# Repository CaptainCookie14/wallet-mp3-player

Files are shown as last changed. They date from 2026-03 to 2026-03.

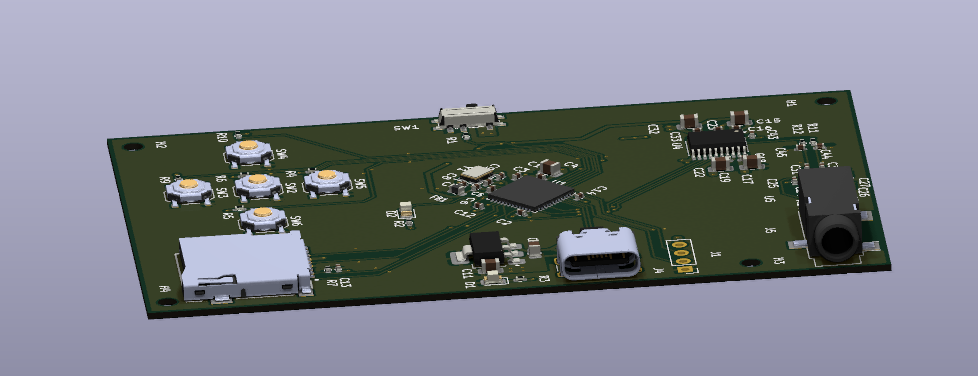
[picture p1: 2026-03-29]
photos/Screenshot 2026-03-28 175809.png

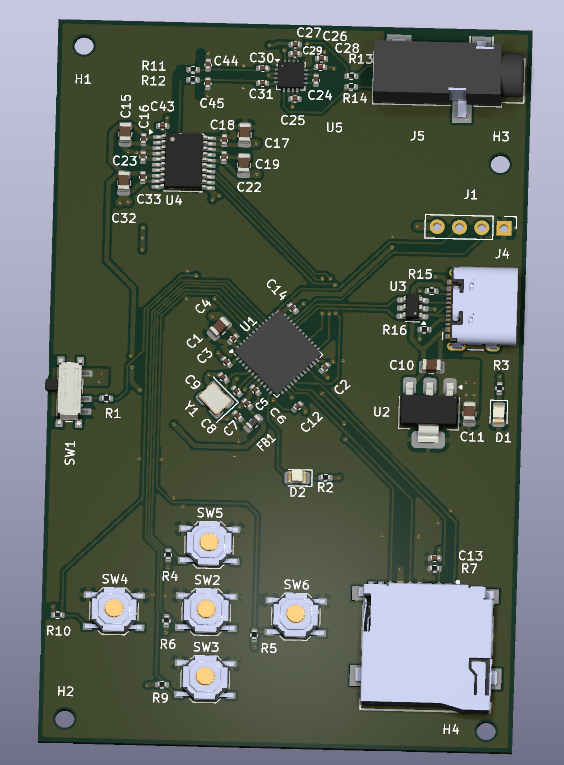
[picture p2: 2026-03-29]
photos/Screenshot 2026-03-28 175754.png

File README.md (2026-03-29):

# wallet-mp3-player
This project is a small, portable MP3 player, designed to be roughly the size of a credit card. This project is all about minimal power consumption, small PCB design, and ease of use for the player.

HOW TO USE IT Insert a micro SD card containing MP3 or WAV files into the device. Turn it on using the battery and play the songs using the buttons. It does not require a phone or computer to play songs. Users can play, pause, and skip songs, and also change the volume using the buttons.



Features

Plays MP3 audio files Ultra-compact PCB design (credit card sized) Button-based controls (play/pause, next, previous, volume) Supports microSD storage for music files Low power consumption for portable devices Optional output for headphones or small speakers

HOW IT WORKS:

It is composed of a microcontroller, which reads the audio files from a storage module, usually a microSD card. The microcontroller then sends the decoded audio to an amplifier for output.

The buttons are always being read by the microcontroller, which controls the state of the player, the songs being played, and the volume.

HARDWARE USED:

-Microcontroller ( STM32F411CEU6x )
- Micro SD card module
- Audio DAC module
- Small audio amplifier
- Tactile and low-profile buttons
- Lithium battery and charging circuit
- PCB designed in KiCad

WIRING/CONNECTIONS:

- Micro SD card module is connected through SPI
- Audio module is connected through I2S or analog pins
- Buttons are connected to digital GPIOs with pull-ups
- Battery is connected through power management circuit



The goal of this project is to create a fully functional, pocket-sized music player that is:

- as thin as possible (under 5mm)
- at least 5 hours of playing time
- able to fit in your wallet
- cheap as possible to make (under 80$ per unit after considering battery, case, shipping & PCB assembly)

The PCB files in this repository were prepared using the JLCPCB KiCad plugin to streamline manufacturing and assembly.

After completing the schematic and PCB layout in KiCad, the plugin was used to:

Generate production-ready Gerber files
Export drill files (Excellon format)
Create a complete BOM (Bill of Materials) with part numbers
Generate a CPL (Pick and Place file) for SMT assembly
Automatically align component footprints with JLCPCB’s supported parts library

i also added the project files and schematic files used for kiCad

Status

Currently in development / testing stage. PCB revisions and firmware improvements are ongoing and am trying to get my first prototype tested.

BOM MATERIALS LIST:
| Ref | Qty | Value | Footprint | LCSC Link |
| --- | --- | --- | --- | --- |
| Y1 | 1 | 16 MHz crystal | 3225 | [https://www.lcsc.com/product-detail/Crystals_YXC-Crystal-CX3225SB16000D0FLJCC_C13738.html](https://www.lcsc.com/product-detail/Crystals_YXC-Crystal-CX3225SB16000D0FLJCC_C13738.html) |
| U5 | 1 | TPA6132A2RTE | WQFN-16 | [https://www.lcsc.com/product-detail/Audio-ICs_Texas-Instruments-TPA6132A2RTE_C2863070.html](https://www.lcsc.com/product-detail/Audio-ICs_Texas-Instruments-TPA6132A2RTE_C2863070.html) |
| U4 | 1 | PCM5102A | TSSOP-20 | [https://www.lcsc.com/product-detail/Audio-ICs_Texas-Instruments-PCM5102A_C1520792.html](https://www.lcsc.com/product-detail/Audio-ICs_Texas-Instruments-PCM5102A_C1520792.html) |
| U3 | 1 | USBLC6-2SC6 | SOT-23-6 | [https://www.lcsc.com/product-detail/TVS-Diodes_STMicroelectronics-USBLC6-2SC6_C7519.html](https://www.lcsc.com/product-detail/TVS-Diodes_STMicroelectronics-USBLC6-2SC6_C7519.html) |
| U2 | 1 | AMS1117 | SOT-223 | [https://www.lcsc.com/product-detail/Linear-Voltage-Regulators_Advanced-Monolithic-Systems-AMS1117-3-3_C6186.html](https://www.lcsc.com/product-detail/Linear-Voltage-Regulators_Advanced-Monolithic-Systems-AMS1117-3-3_C6186.html) |
| U1 | 1 | STM32F411CEUx | QFN-48 | [https://www.lcsc.com/product-detail/Microcontrollers-MCU-ST-Microelectronics-STM32F411CEUx_C60420.html](https://www.lcsc.com/product-detail/Microcontrollers-MCU-ST-Microelectronics-STM32F411CEUx_C60420.html) |
| SW2–SW6 | 5 | Tactile switch | SMD push button | [https://www.lcsc.com/product-detail/Tactile-Switches_XKB-TS-1187A_C318884.html](https://www.lcsc.com/product-detail/Tactile-Switches_XKB-TS-1187A_C318884.html) |
| SW1 | 1 | SPDT switch | PCM12 | [https://www.lcsc.com/product-detail/Slide-Switches_CW-PCM12_C109335.html](https://www.lcsc.com/product-detail/Slide-Switches_CW-PCM12_C109335.html) |
| R15,R16 | 2 | 5.1kΩ | 0402 | [https://www.lcsc.com/product-detail/Chip-Resistor-Surface-Mount_YAGEO-RC0402FR-075K1L_C25905.html](https://www.lcsc.com/product-detail/Chip-Resistor-Surface-Mount_YAGEO-RC0402FR-075K1L_C25905.html) |
| R13,R14 | 2 | 10Ω | 0402 | [https://www.lcsc.com/product-detail/Chip-Resistor-Surface-Mount_YAGEO-RC0402FR-0710RL_C25077.html](https://www.lcsc.com/product-detail/Chip-Resistor-Surface-Mount_YAGEO-RC0402FR-0710RL_C25077.html) |
| R11,R12 | 2 | 450Ω | 0402 | [https://www.lcsc.com/product-detail/Chip-Resistor-Surface-Mount_YAGEO-RC0402FR-07450RL_C25117.html](https://www.lcsc.com/product-detail/Chip-Resistor-Surface-Mount_YAGEO-RC0402FR-07450RL_C25117.html) |
| R2,R3 | 2 | 1.5kΩ | 0402 | [https://www.lcsc.com/product-detail/Chip-Resistor-Surface-Mount_YAGEO-RC0402FR-071K5L_C25867.html](https://www.lcsc.com/product-detail/Chip-Resistor-Surface-Mount_YAGEO-RC0402FR-071K5L_C25867.html) |
| R1,R4–R7,R9,R10 | 7 | 10kΩ | 0402 | [https://www.lcsc.com/product-detail/Chip-Resistor-Surface-Mount_YAGEO-RC0402FR-0710KL_C25744.html](https://www.lcsc.com/product-detail/Chip-Resistor-Surface-Mount_YAGEO-RC0402FR-0710KL_C25744.html) |
| J5 | 1 | 3.5mm audio jack  | SMT | [https://www.lcsc.com/product-detail/Audio-Connectors_CUI-Devices-SJ-3523-SMT_C4991872.html](https://www.lcsc.com/product-detail/Audio-Connectors_CUI-Devices-SJ-3523-SMT_C4991872.html) |
| J4 | 1 | USB-C receptacle  | 16P USB2.0 | [https://www.lcsc.com/product-detail/USB-Connectors_XKB-Connectivity-U262-16XN-4BVC11_C2894897.html](https://www.lcsc.com/product-detail/USB-Connectors_XKB-Connectivity-U262-16XN-4BVC11_C2894897.html) |
| J2 | 1 | Micro SD socket | TF-01A | [https://www.lcsc.com/product-detail/Memory-Card-Sockets_Jinling-Group-TF-01A_C91145.html](https://www.lcsc.com/product-detail/Memory-Card-Sockets_Jinling-Group-TF-01A_C91145.html) |
| J1 | 1 | 4-pin header | 2.54mm | [https://www.lcsc.com/product-detail/Pin-Header-Sockets_Generic-2-54mm-pin-header_CNA.html](https://www.lcsc.com/product-detail/Pin-Header-Sockets_Generic-2-54mm-pin-header_CNA.html) |
| FB1 | 1 | 120Ω ferrite bead | 0603 | [https://www.lcsc.com/product-detail/Ferrite-Beads_Murata-BLM18AG121SN1D_C76892.html](https://www.lcsc.com/product-detail/Ferrite-Beads_Murata-BLM18AG121SN1D_C76892.html) |
| D1,D2 | 2 | LED | 0805 | [https://www.lcsc.com/product-detail/LED-Indication_YONGYUTAI-0805-LED_C2290.html](https://www.lcsc.com/product-detail/LED-Indication_YONGYUTAI-0805-LED_C2290.html) |
| C44,C45 | 2 | 2.2nF | 0402 | [https://www.lcsc.com/product-detail/Ceramic-Capacitors_YAGEO-CC0402KRX7R7BB222_C1531.html](https://www.lcsc.com/product-detail/Ceramic-Capacitors_YAGEO-CC0402KRX7R7BB222_C1531.html) |
| C23,C26,C27,C43 | 4 | 2.2µF | 0402 | [https://www.lcsc.com/product-detail/Ceramic-Capacitors_YAGEO-CC0402MRX5R5BB225_C12530.html](https://www.lcsc.com/product-detail/Ceramic-Capacitors_YAGEO-CC0402MRX5R5BB225_C12530.html) |
| C10,C11 | 2 | 22µF | 0805 | [https://www.lcsc.com/product-detail/Ceramic-Capacitors_Murata-GRM21BR61A226ME44_C45783.html](https://www.lcsc.com/product-detail/Ceramic-Capacitors_Murata-GRM21BR61A226ME44_C45783.html) |
| C8,C9 | 2 | 10pF | 0402 | [https://www.lcsc.com/product-detail/Ceramic-Capacitors_YAGEO-CC0402JRNPO9BN100_C32949.html](https://www.lcsc.com/product-detail/Ceramic-Capacitors_YAGEO-CC0402JRNPO9BN100_C32949.html) |
| C6,C7,C24,C25,C30,C31 | 6 | 1µF | 0402 | [https://www.lcsc.com/product-detail/Ceramic-Capacitors_YAGEO-CC0402MRX5R5BB105_C52923.html](https://www.lcsc.com/product-detail/Ceramic-Capacitors_YAGEO-CC0402MRX5R5BB105_C52923.html) |
| C5 | 1 | 10nF | 0402 | [https://www.lcsc.com/product-detail/Ceramic-Capacitors_YAGEO-CC0402KRX7R9BB103_C15195.html](https://www.lcsc.com/product-detail/Ceramic-Capacitors_YAGEO-CC0402KRX7R9BB103_C15195.html) |
| C4,C15,C17,C19,C32 | 5 | 10µF | 0805 | [https://www.lcsc.com/product-detail/Ceramic-Capacitors_Murata-GRM21BR61A106KE19_C15850.html](https://www.lcsc.com/product-detail/Ceramic-Capacitors_Murata-GRM21BR61A106KE19_C15850.html) |
| C1–C3,C12–C14,C16,C18,C22,C28–C29,C33 | 12  | 100nF | 0402 | [https://www.lcsc.com/product-detail/Ceramic-Capacitors_YAGEO-CC0402KRX7R7BB104_C1525.html](https://www.lcsc.com/product-detail/Ceramic-Capacitors_YAGEO-CC0402KRX7R7BB104_C1525.html) |



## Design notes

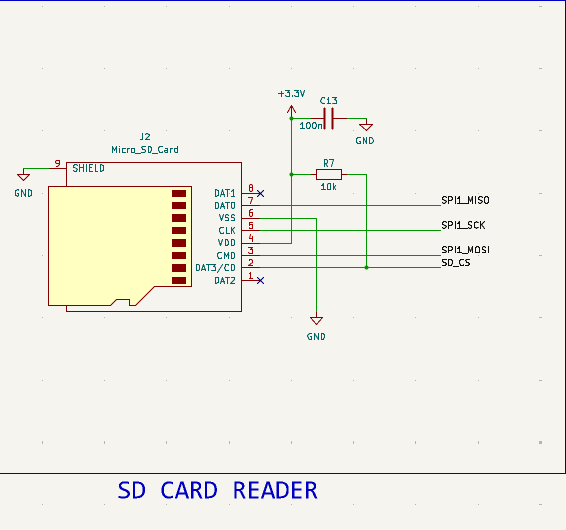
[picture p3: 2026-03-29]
photos/Screenshot 2026-03-28 175607.png

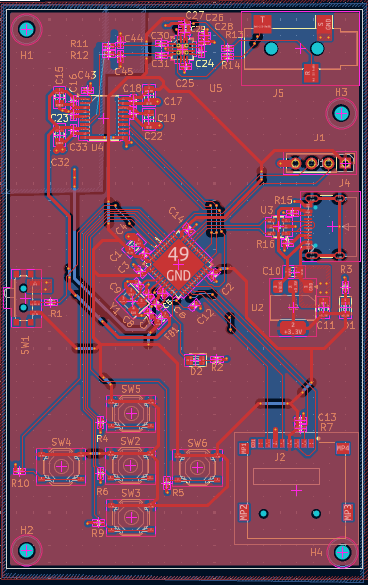
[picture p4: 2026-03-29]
photos/Screenshot 2026-03-28 175625.png

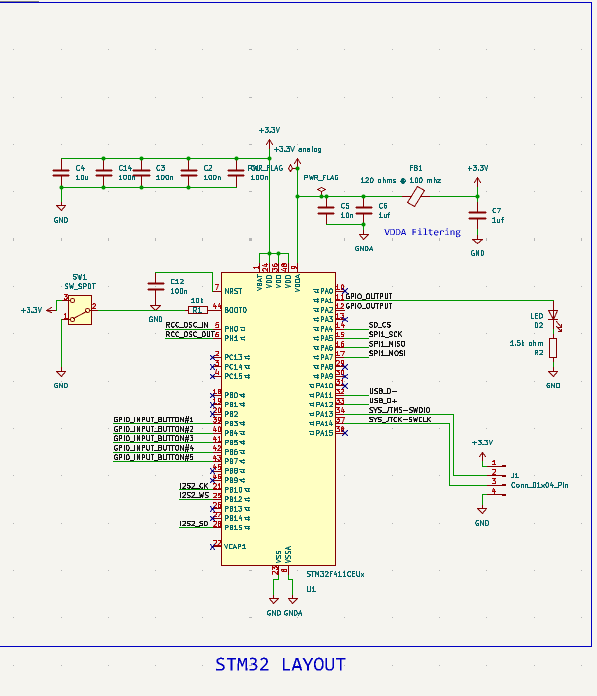
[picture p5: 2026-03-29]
photos/Screenshot 2026-03-28 175323.png

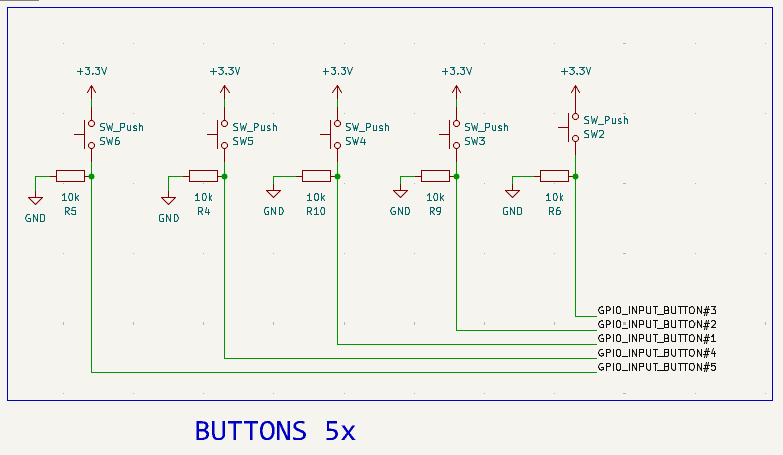
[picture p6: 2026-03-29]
photos/Screenshot 2026-03-28 175536.png

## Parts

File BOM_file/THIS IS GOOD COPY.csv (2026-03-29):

Reference | Qty | Value | DNP | Exclude from BOM | Exclude from Board | Footprint | Datasheet | LSCS
Y1 | 1 | 16mhz |  |  |  | Crystal:Crystal_SMD_3225-4Pin_3.2x2.5mm |  | C13738
U5 | 1 | TPA6132A2RTE |  |  |  | Package_DFN_QFN:WQFN-16-1EP_3x3mm_P0.5mm_EP1.6x1.6mm_ThermalVias | https://www.ti.com/lit/ds/symlink/tpa6132a2.pdf | C2863070
U4 | 1 | PCM5102A |  |  |  | Package_SO:TSSOP-20_4.4x6.5mm_P0.65mm | https://www.ti.com/lit/ds/symlink/pcm5102a.pdf | C1520792
U3 | 1 | USBLC6-2SC6 |  |  |  | Package_TO_SOT_SMD:SOT-23-6 | https://www.st.com/resource/en/datasheet/usblc6-2.pdf | C7519
U2 | 1 | AMS1117 |  |  |  | Package_TO_SOT_SMD:SOT-223-3_TabPin2 | http://www.advanced-monolithic.com/pdf/ds1117.pdf | C6186
U1 | 1 | STM32F411CEUx |  |  |  | Package_DFN_QFN:QFN-48-1EP_7x7mm_P0.5mm_EP5.6x5.6mm | https://www.st.com/resource/en/datasheet/stm32f411ce.pdf | C60420
SW2,SW3,SW4,SW5,SW6 | 5 | SW_Push |  |  |  | Button_Switch_SMD:SW_Push_1P1T_XKB_TS-1187A |  | C318884
SW1 | 1 | SW_SPDT |  |  |  | Button_Switch_SMD:SW_SPDT_PCM12 |  | C109335
R15,R16 | 2 | 5k1 |  |  |  | Resistor_SMD:R_0402_1005Metric |  | C25905
R13,R14 | 2 | 10ohm |  |  |  | Resistor_SMD:R_0402_1005Metric |  | C25077
R11,R12 | 2 | 450 |  |  |  | Resistor_SMD:R_0402_1005Metric |  | C25117
R2,R3 | 2 | 1.5k ohm |  |  |  | Resistor_SMD:R_0402_1005Metric |  | C25867
R1,R4,R5,R6,R7,R9,R10 | 7 | 10k |  |  |  | Resistor_SMD:R_0402_1005Metric |  | C25744
J5 | 1 | AudioJack3 |  |  |  | Connector_Audio:Jack_3.5mm_CUI_SJ-3523-SMT_Horizontal |  | C4991872
J4 | 1 | USB_C_Receptacle_USB2.0_16P |  |  |  | Connector_USB:USB_C_Receptacle_HCTL_HC-TYPE-C-16P-01A | https://www.usb.org/sites/default/files/documents/usb_type-c.zip | C2894897
J2 | 1 | Micro_SD_Card |  |  |  | sd_card_socket:TF-01A | https://www.we-online.com/components/products/datasheet/693072010801.pdf | C91145
J1 | 1 | Conn_01x04_Pin |  |  |  | Connector_PinHeader_2.54mm:PinHeader_1x04_P2.54mm_Vertical
FB1 | 1 | 120 ohms @ 100 mhz |  |  |  | Inductor_SMD:L_0603_1608Metric |  | C76892
D1,D2 | 2 | LED |  |  |  | LED_SMD:LED_0805_2012Metric |  | C2290
C44,C45 | 2 | 2.2n |  |  |  | Capacitor_SMD:C_0402_1005Metric |  | C1531
C23,C26,C27,C43 | 4 | 2u2 |  |  |  | Capacitor_SMD:C_0402_1005Metric |  | C12530
C10,C11 | 2 | 22u |  |  |  | Capacitor_SMD:C_0805_2012Metric |  | C45783
C8,C9 | 2 | 10p |  |  |  | Capacitor_SMD:C_0402_1005Metric |  | C32949
C6,C7,C24,C25,C30,C31 | 6 | 1uf |  |  |  | Capacitor_SMD:C_0402_1005Metric |  | C52923
C5 | 1 | 10n |  |  |  | Capacitor_SMD:C_0402_1005Metric |  | C15195
C4,C15,C17,C19,C32 | 5 | 10u |  |  |  | Capacitor_SMD:C_0805_2012Metric |  | C15850
C1,C2,C3,C12,C13,C14,C16,C18,C22,C28,C29,C33 | 12 | 100n |  |  |  | Capacitor_SMD:C_0402_1005Metric |  | C1525

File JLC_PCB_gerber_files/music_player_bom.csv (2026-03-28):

Designator | Footprint | Quantity | Value | LCSC Part #
C1, C12, C13, C14, C16, C18, C2, C22, C28, C29, C3, C33 | 0402 | 12 | 100n
C10, C11 | 0805 | 2 | 22u
C15, C17, C19, C32, C4 | 0805 | 5 | 10u
C23, C26, C27, C43 | 0402 | 4 | 2u2
C24, C25, C30, C31, C6, C7 | 0402 | 6 | 1uf
C44, C45 | 0402 | 2 | 2.2n
C5 | 0402 | 1 | 10n
C8, C9 | 0402 | 2 | 10p
D1, D2 | 0805 | 2 | LED
FB1 | 0603 | 1 | 120 ohms @ 100 mhz
J1 | PinHeader_1x04_P2.54mm_Vertical | 1 | Conn_01x04_Pin
J2 | TF-01A | 1 | Micro_SD_Card
J4 | USB_C_Receptacle_HCTL_HC-TYPE-C-16P-01A | 1 | USB_C_Receptacle_USB2.0_16P
J5 | Jack_3.5mm_CUI_SJ-3523-SMT_Horizontal | 1 | AudioJack3
R1, R10, R4, R5, R6, R7, R9 | 0402 | 7 | 10k
R11, R12 | 0402 | 2 | 450
R13, R14 | 0402 | 2 | 10ohm
R15, R16 | 0402 | 2 | 5k1
R2, R3 | 0402 | 2 | 1.5k ohm
SW1 | SW_SPDT_PCM12 | 1 | SW_SPDT
SW2, SW3, SW4, SW5, SW6 | SW_Push_1P1T_XKB_TS-1187A | 5 | SW_Push
U1 | QFN-48-1EP_7x7mm_P0.5mm_EP5.6x5.6mm | 1 | STM32F411CEUx
U2 | SOT-223-3_TabPin2 | 1 | AMS1117
U3 | SOT-23-6 | 1 | USBLC6-2SC6
U4 | TSSOP-20_4.4x6.5mm_P0.65mm | 1 | PCM5102A
U5 | WQFN-16-1EP_3x3mm_P0.5mm_EP1.6x1.6mm_ThermalVias | 1 | TPA6132A2RTE
Y1 | Crystal_SMD_3225-4Pin_3.2x2.5mm | 1 | 16mhz

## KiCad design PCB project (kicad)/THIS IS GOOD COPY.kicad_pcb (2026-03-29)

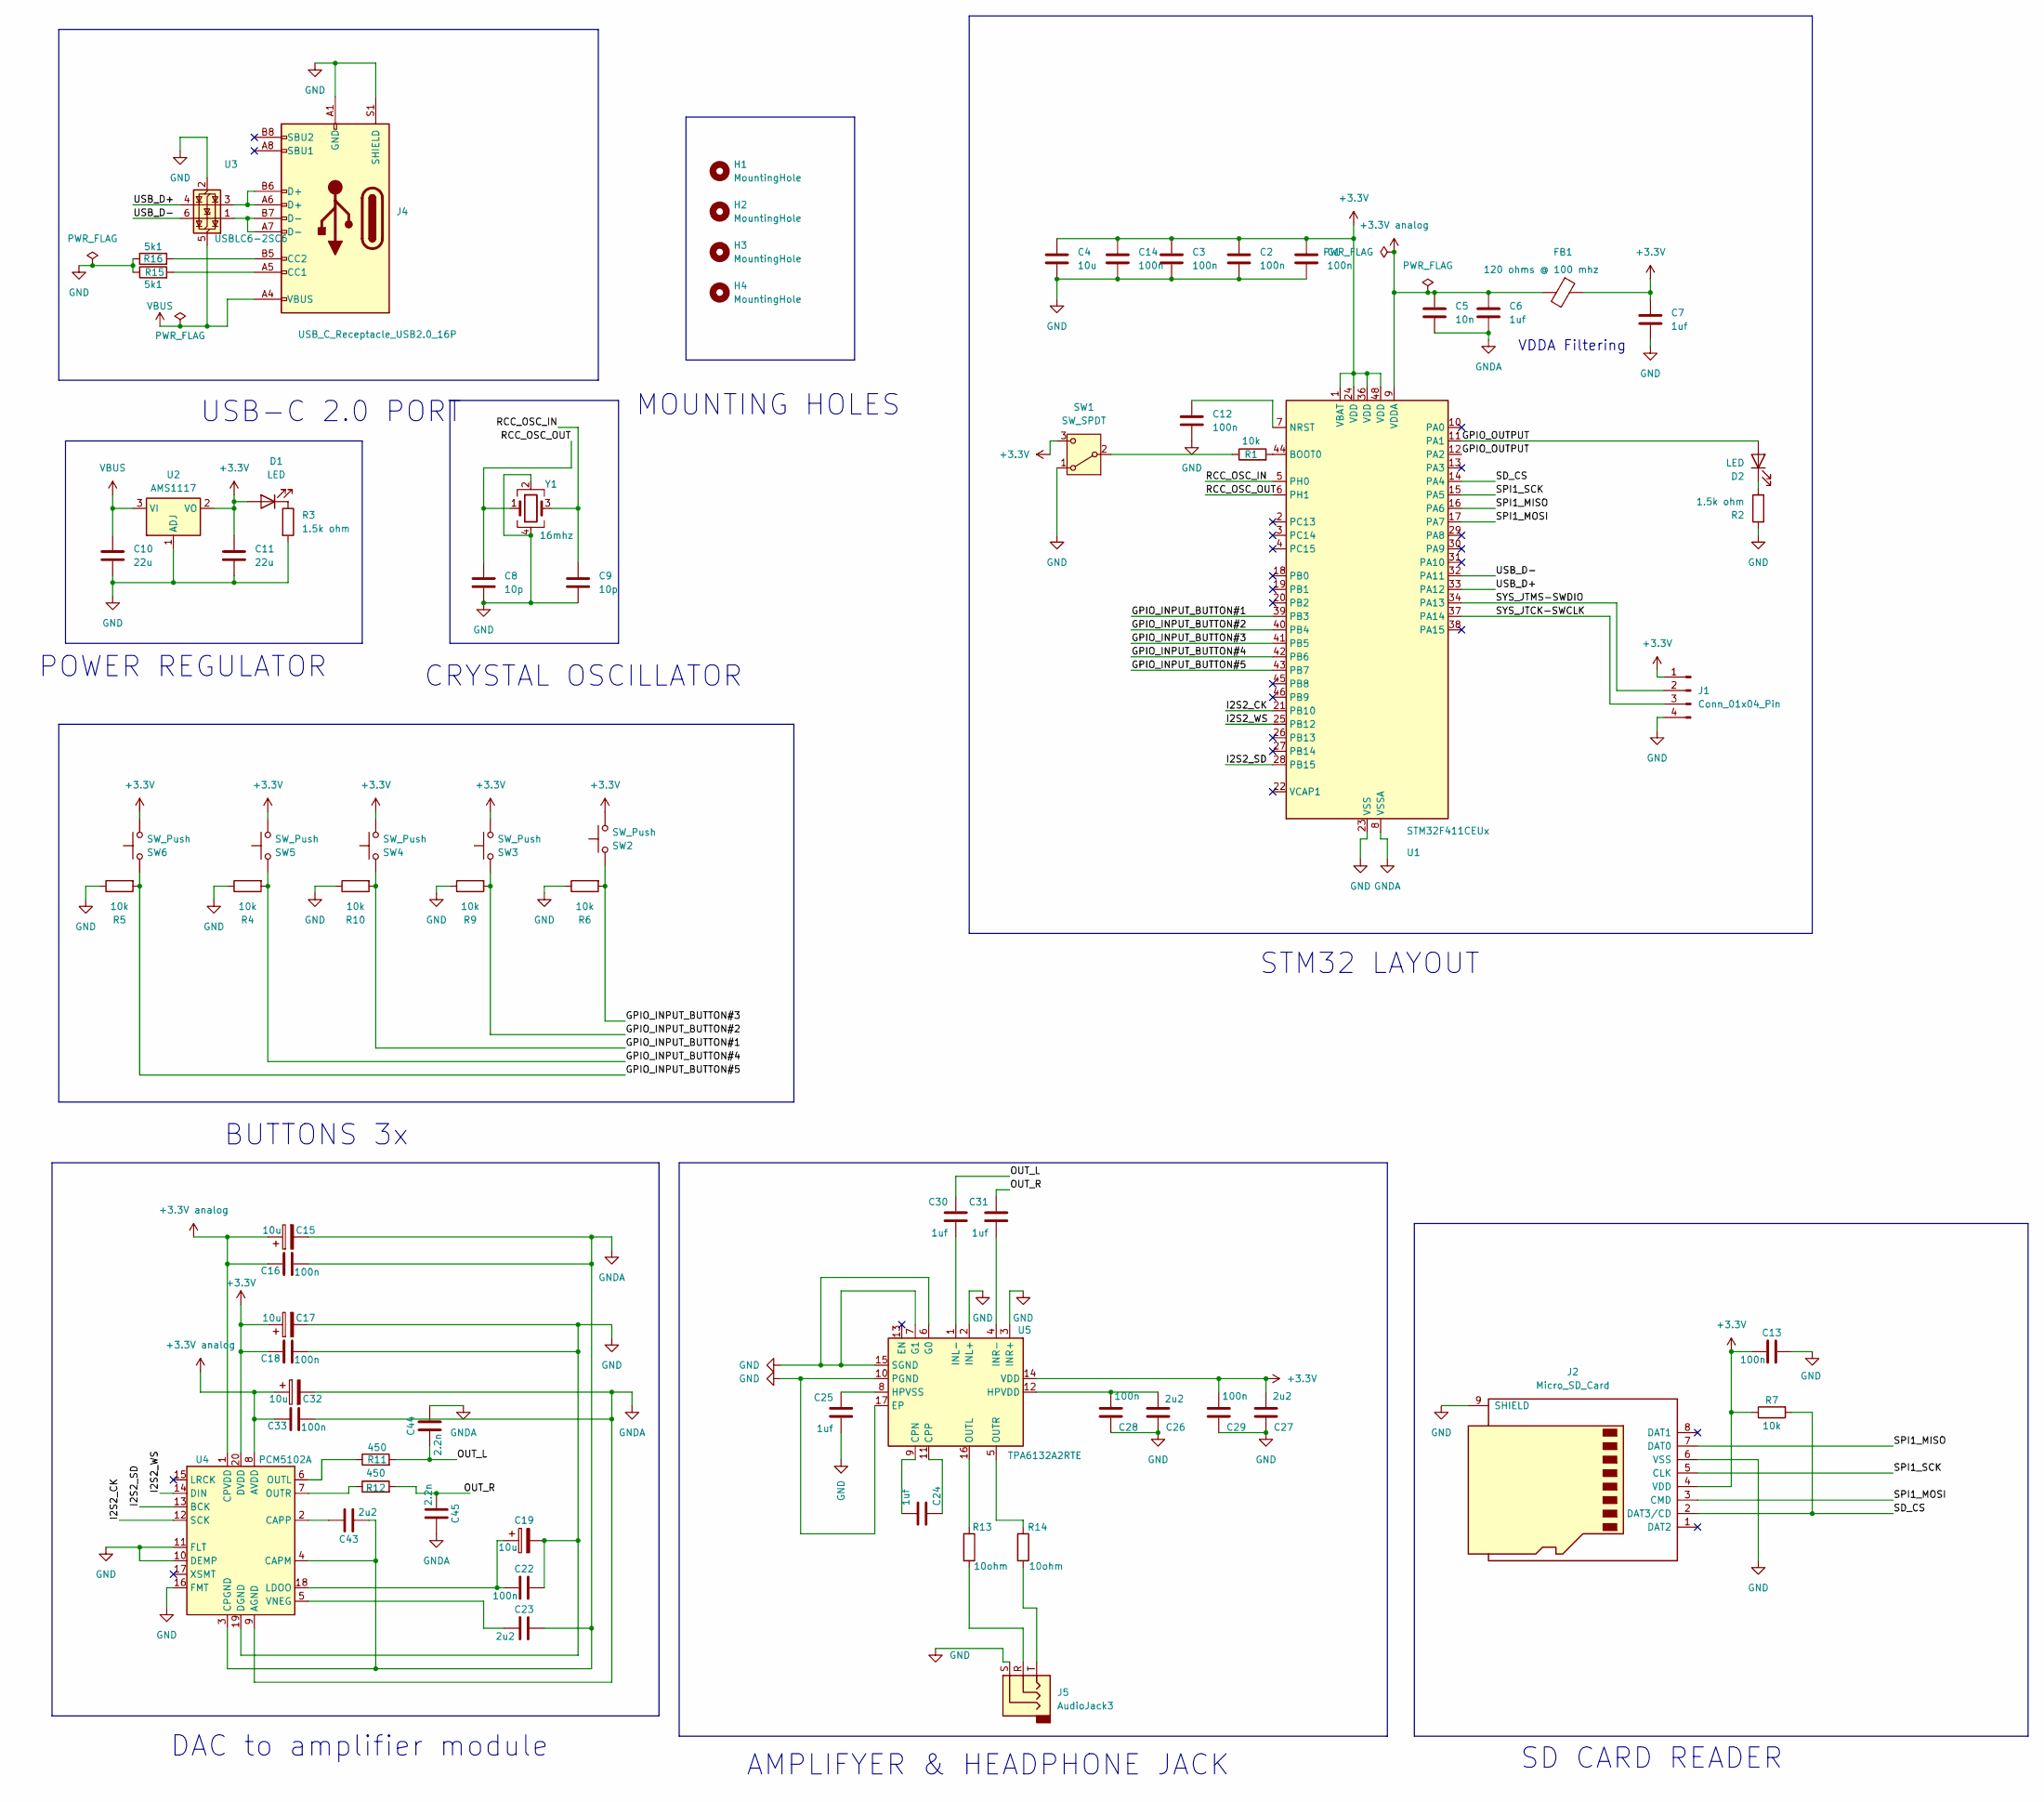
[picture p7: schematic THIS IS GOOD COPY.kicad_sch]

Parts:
C1, C2, C3, C12, C13, C14, C16, C18, C22, C28, C29, C33: 100n; C_0402_1005Metric
C4, C15, C17, C19, C32: 10u; C_0805_2012Metric
C5: 10n; C_0402_1005Metric
C6, C7, C24, C25, C30, C31: 1uf; C_0402_1005Metric
C8, C9: 10p; C_0402_1005Metric
C10, C11: 22u; C_0805_2012Metric
C23, C26, C27, C43: 2u2; C_0402_1005Metric
C44, C45: 2.2n; C_0402_1005Metric
D1, D2: LED; LED_0805_2012Metric
FB1: 120 ohms @ 100 mhz; L_0603_1608Metric
H1, H2, H3, H4: MountingHole; MountingHole_2.2mm_M2
J1: Conn_01x04_Pin; PinHeader_1x04_P2.54mm_Vertical
J2: Micro_SD_Card; TF-01A
J4: USB_C_Receptacle_USB2.0_16P; USB_C_Receptacle_HCTL_HC-TYPE-C-16P-01A
J5: AudioJack3; Jack_3.5mm_CUI_SJ-3523-SMT_Horizontal
R1, R4, R5, R6, R7, R9, R10: 10k; R_0402_1005Metric
R2, R3: 1.5k ohm; R_0402_1005Metric
R11, R12: 450; R_0402_1005Metric
R13, R14: 10ohm; R_0402_1005Metric
R15, R16: 5k1; R_0402_1005Metric
SW1: SW_SPDT; SW_SPDT_PCM12
SW2, SW3, SW4, SW5, SW6: SW_Push; SW_Push_1P1T_XKB_TS-1187A
U1: STM32F411CEUx; QFN-48-1EP_7x7mm_P0.5mm_EP5.6x5.6mm
U2: AMS1117; SOT-223-3_TabPin2
U3: USBLC6-2SC6; SOT-23-6
U4: PCM5102A; TSSOP-20_4.4x6.5mm_P0.65mm
U5: TPA6132A2RTE; WQFN-16-1EP_3x3mm_P0.5mm_EP1.6x1.6mm_ThermalVias
Y1: 16mhz; Crystal_SMD_3225-4Pin_3.2x2.5mm

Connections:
+3.3V: C1.1, C2.1, C3.1, C4.1, C7.1, C11.1, C13.2, C14.1, C17.1, C18.1, C27.2, C29.2, D1.2 (A), FB1.1, J1.1, J2.4 (VDD), R7.1, SW1.3 (C), SW2.1, SW3.1, SW4.1, SW5.1, SW6.1, U1.1 (VBAT), U1.24 (VDD), U1.36 (VDD), U1.48 (VDD), U2.2 (VO), U4.20 (DVDD), U5.14 (VDD)
+3.3V analog: C5.1, C6.1, C15.1, C16.1, C32.1, C33.1, FB1.2, U1.9 (VDDA), U4.1 (CPVDD), U4.8 (AVDD)
/GPIO_INPUT_BUTTON#1: R10.2, SW4.2, U1.39 (PB3)
/GPIO_INPUT_BUTTON#2: R9.2, SW3.2, U1.40 (PB4)
/GPIO_INPUT_BUTTON#3: R6.2, SW2.2, U1.41 (PB5)
/GPIO_INPUT_BUTTON#4: R4.2, SW5.2, U1.42 (PB6)
/GPIO_INPUT_BUTTON#5: R5.2, SW6.2, U1.43 (PB7)
/GPIO_OUTPUT: D2.2 (A), U1.11 (PA1), U1.12 (PA2)
/I2S2_CK: U1.21 (PB10), U4.12 (SCK)
/I2S2_SD: U1.28 (PB15), U4.13 (BCK)
/I2S2_WS: U1.25 (PB12), U4.14 (DIN)
/OUT_L: C30.1, C44.2, R11.2
/OUT_R: C31.1, C45.2, R12.2
/RCC_OSC_IN: C9.1, U1.5 (PH0), Y1.3
/RCC_OSC_OUT: C8.1, U1.6 (PH1), Y1.1
/SD_CS: J2.2 (DAT3/CD), R7.2, U1.14 (PA4)
/SPI1_MISO: J2.7 (DAT0), U1.16 (PA6)
/SPI1_MOSI: J2.3 (CMD), U1.17 (PA7)
/SPI1_SCK: J2.5 (CLK), U1.15 (PA5)
/SYS_JTCK-SWCLK: J1.3, U1.37 (PA14)
/SYS_JTMS-SWDIO: J1.2, U1.34 (PA13)
/USB_D+: U1.33 (PA12), U3.4 (I/O2)
/USB_D-: U1.32 (PA11), U3.6 (I/O1)
GND: C1.2, C2.2, C3.2, C4.2, C7.2, C8.2, C9.2, C10.2, C11.2, C12.2, C13.1, C14.2, C17.2, C18.2, C19.2, C22.1, C25.2, C26.1, C27.1, C28.1, C29.1, J1.4, J2.6 (VSS), J2.9 (SHIELD), J4.A1 (GND), J4.A12 (GND), J4.B1 (GND), J4.B12 (GND), J4.S1 (SHIELD), J5.S, R2.1, R3.2, R4.1, R5.1, R6.1, R9.1, R10.1, R15.1, R16.1, SW1.1 (A), U1.23 (VSS), U1.35 (VSS), U1.47 (VSS), U1.49 (VSS), U2.1 (ADJ), U3.2 (GND), U4.10 (DEMP), U4.11 (FLT), U4.16 (FMT), U4.19 (DGND), U5.2 (INL+), U5.3 (INR+), U5.6 (G0), U5.7 (G1), U5.10 (PGND), U5.15 (SGND), U5.17 (EP), Y1.2, Y1.4
GNDA: C5.2, C6.2, C15.2, C16.2, C23.1, C32.2, C33.2, C43.2, C44.1, C45.1, U1.8 (VSSA), U4.3 (CPGND), U4.4 (CAPM), U4.9 (AGND)
unnamed: D1.1 (K), R3.1
unnamed: D2.1 (K), R2.2
unnamed: J4.A5 (CC1), R16.2
unnamed: J4.B5 (CC2), R15.2
unnamed: J4.A6 (D+), J4.B6 (D+), U3.3 (I/O2)
unnamed: J4.A7 (D-), J4.B7 (D-), U3.1 (I/O1)
unnamed: J5.R, R13.2
unnamed: J5.T, R14.2
unnamed: R1.1, SW1.2 (B)
unnamed: R1.2, U1.44 (BOOT0)
unnamed: C12.1, U1.7 (NRST)
unnamed: C43.1, U4.2 (CAPP)
unnamed: C19.1, C22.2, U4.18 (LDOO)
unnamed: R11.1, U4.6 (OUTL)
unnamed: R12.1, U4.7 (OUTR)
unnamed: C23.2, U4.5 (VNEG)
unnamed: C24.2, U5.9 (CPN)
unnamed: C24.1, U5.11 (CPP)
unnamed: C26.2, C28.2, U5.12 (HPVDD)
unnamed: C25.1, U5.8 (HPVSS)
unnamed: C30.2, U5.1 (INL-)
unnamed: C31.2, U5.4 (INR-)
unnamed: R13.1, U5.16 (OUTL)
unnamed: R14.1, U5.5 (OUTR)
VBUS: C10.1, J4.A4 (VBUS), J4.A9 (VBUS), J4.B4 (VBUS), J4.B9 (VBUS), U2.3 (VI), U3.5 (VBUS)

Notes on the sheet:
DAC to amplifier module
CRYSTAL OSCILLATOR
AMPLIFYER & HEADPHONE JACK
POWER REGULATOR
VDDA Filtering
SD CARD READER
MOUNTING HOLES
BUTTONS 3x
USB-C 2.0 PORT
STM32 LAYOUT

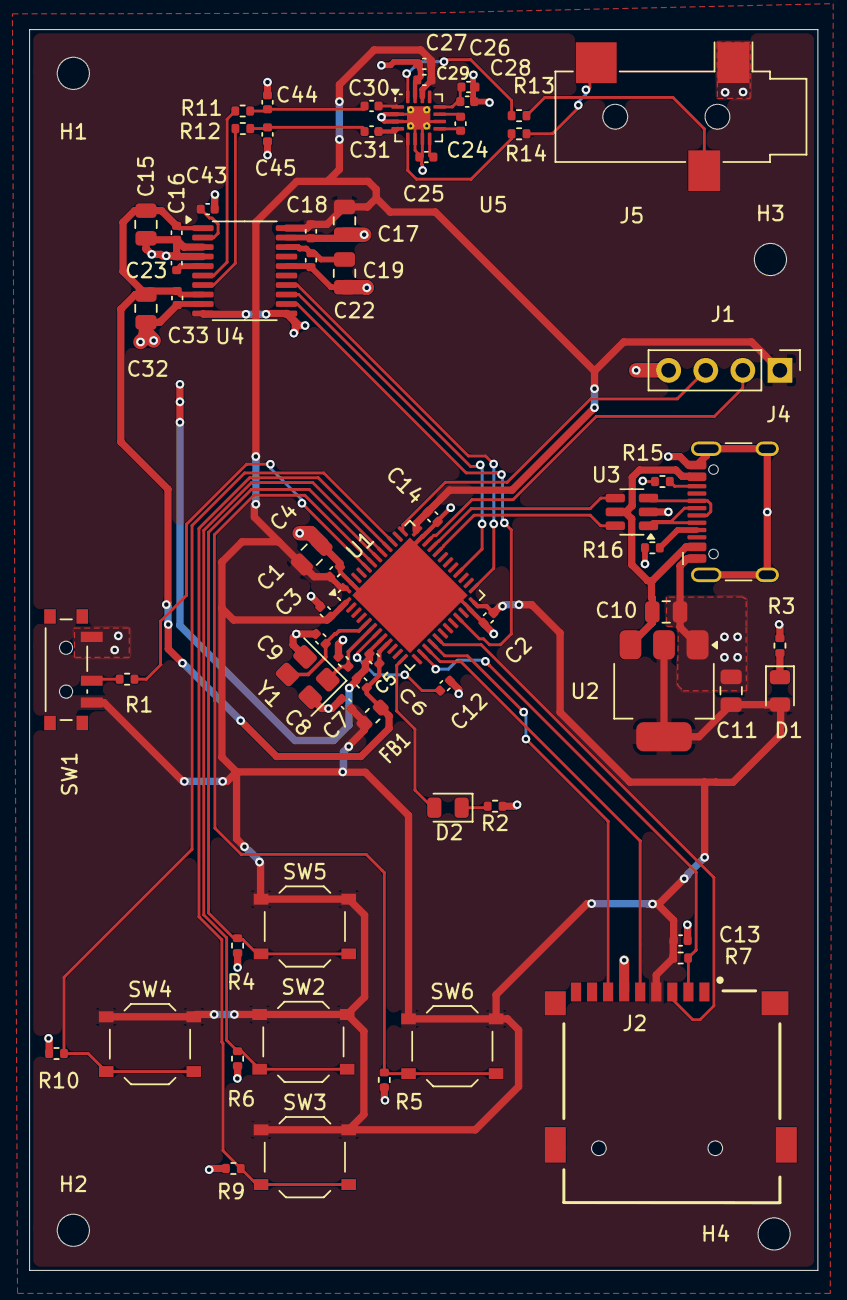
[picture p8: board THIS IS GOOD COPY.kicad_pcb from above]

Board: 2 copper layers, 54.0 x 85.0 mm, 72 parts (0 on the bottom side), 50 nets.

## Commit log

2026-03-28 Add files via upload
    these files are configured for JLC PCB
    [music_player_bom.csv, music_player_designators.csv, music_player_positions.csv]
2026-03-29 Add BOM materials list to README
    Added a BOM materials list with component details.
2026-03-29 Revise BOM materials list and add LCSC links
    Updated BOM materials list with improved formatting and added LCSC links for components.
2026-03-29 Create BOM
2026-03-29 Revise README for improved clarity and formatting
    Updated features, hardware used, and wiring sections for clarity and consistency.
